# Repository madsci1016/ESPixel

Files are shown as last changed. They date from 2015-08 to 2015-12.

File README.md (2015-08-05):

# ESPixel
ESP8266 based WIFI pixel drivers. A design for both GECE (GE Color Effects) and standard WS2811 pixels. 

This work is licensed under a Creative Commons Attribution-NonCommercial 4.0 International License. This work is distributed in the hope that it will be useful, but WITHOUT ANY WARRANTY; without even the implied warranty of MERCHANTABILITY or FITNESS FOR A PARTICULAR PURPOSE.

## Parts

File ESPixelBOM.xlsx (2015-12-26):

Description | Part No | Vendor | Qty | Price/Ea | Total | 100 QTY price/ea | 100 qty price tot | Link
3.3V Reg | 497-1491-5-ND | digikey.com | 1 | 0.62 | 0.62 | 0.27 | 27
5V Reg (for 12V pixels) | LM78L05ACZFS-ND | digikey.com | 1 | 0.43 | 0.43 | 0.198 | 19.8
Capacitor Pol | 1189-2375-ND | digikey.com | 1 | 0.29 | 0.29 | 0.11008 | 11.008
Capacitor | 399-9776-ND | digikey.com | 1 | 0.29 | 0.29 | 0.1209 | 12.09
Mosfet | zvn3306a-nd | digikey.com | 1 | 0.73 | 0.73 | 0.493 | 49.3
resistor | CF18JT330RCT-ND | digikey.com | 2 | 0.1 | 0.2 | 0.02 | 4
Header | S1011E-36-ND | digikey.com | 0.33 | 2.34 | 0.7722 | 1.72 | 56.76
Diode | 1N4148TACT-ND | digikey.com | 1 | 0.1 | 0.1 | 0.0224 | 2.24
Button | 450-1650-ND | digikey.com | 1 | 0.11 | 0.11 | 0.08 | 8
8 pin socket | 1212-1231-ND | digikey.com | 1 | 0.8 | 0.8 | 0.57 | 57
Box | HM1102-ND | digikey.com | 1 | 4.19 | 4.19
Gland | 7489K12 (http://www.mcmaster.com/nav/enter.asp?partnum=7489K12) | Mcmaster-carr | 1 | 6.47 | 6.47
Gland | 7807K31 (http://www.mcmaster.com/nav/enter.asp?partnum=7807K31) | Mcmaster-carr | 1 | 3.74 | 3.74
 |  |  |  |  | 0 |  | 0
PCB |  | seeed | 0.1 | 10 | 1 | 100 | 100
 |  |  |  |  | 0 |  | 0
 |  |  |  |  | 0 |  | 0
WIFI |  | Sparkfun | 1 | 5.56 | 5.56 | 5.56 | 556
 |  |  |  |  | 0 |  | 0
 |  |  |  |  | 0 |  | 0
 |  |  |  |  | 0 |  | 0
 |  |  |  |  |  |  | 0
 |  |  |  | Total | 25.3022 |  | 903.198

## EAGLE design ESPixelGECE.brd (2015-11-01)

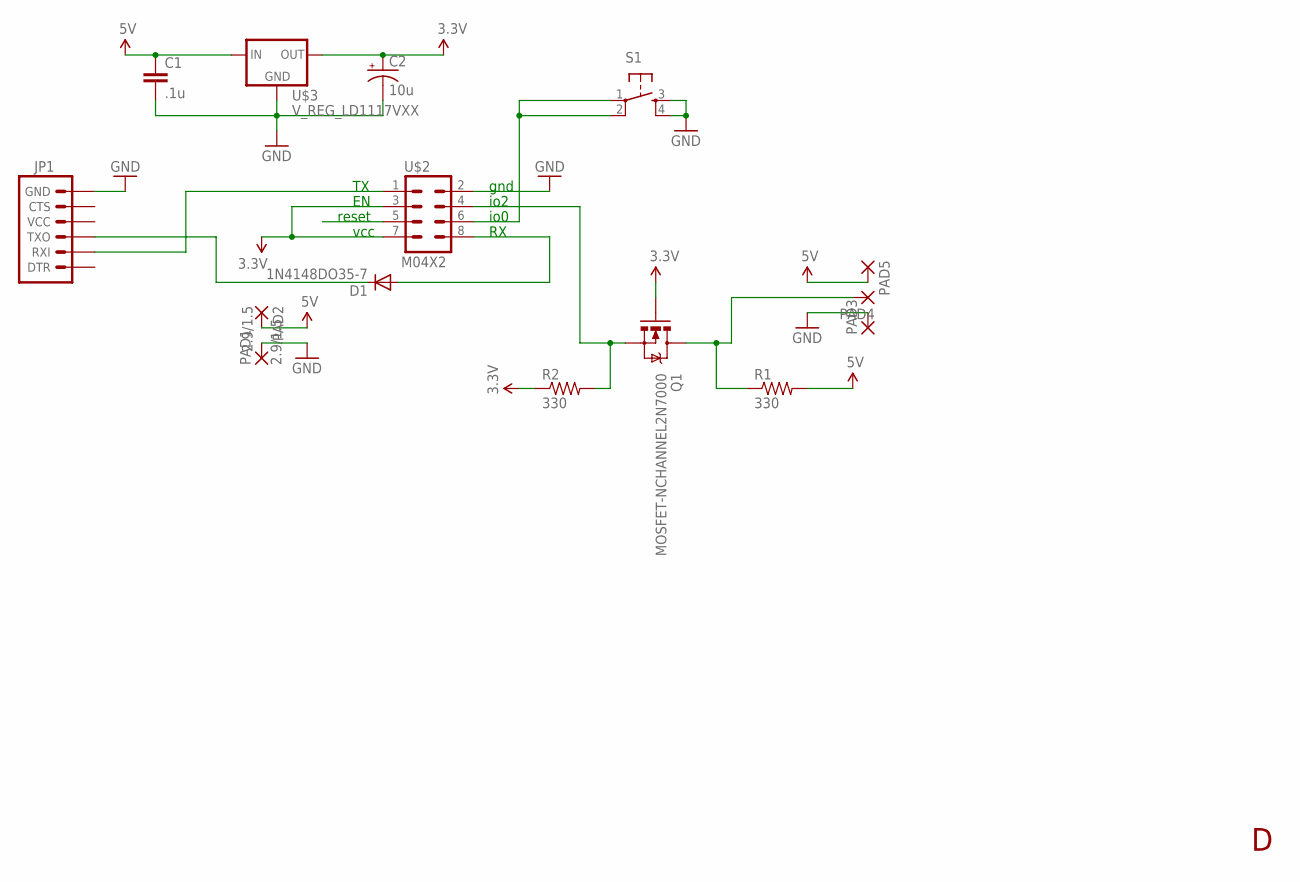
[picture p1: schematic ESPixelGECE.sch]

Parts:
C1: .1u; CAP-PTH-SMALLEZ
C2: 10u; CPOL-RADIAL-10UF-25V
D1: 1N4148DO35-7; DO35-7
JP1: ARDUINO_SERIAL_PROGRAMLOCK; 1X06_LOCK
PAD1, PAD2: 2.9/1.5
PAD3, PAD4, PAD5: 2,15/1,0
Q1: MOSFET-NCHANNEL2N7000; TO-92
R1, R2: 330; AXIAL-0.3EZ
S1: TAC_SWITCHPTH; TACTILE-PTH
U$2: M04X2; 2X4
U$3: V_REG_LD1117VXX; 78XXL

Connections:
3.3V: C2.1 (+), Q1.2 (G), R2.P$1 (1), U$2.3, U$2.7, U$3.GND (OUT)
5V: C1.1, PAD2.1, PAD5.1, R1.P$2 (2), U$3.OUT (IN)
GND: C1.2, C2.2 (-), JP1.6 (GND), PAD1.1, PAD3.1, S1.3, S1.4, U$2.2, U$3.IN (GND)
unnamed: JP1.2 (RXI), U$2.1
unnamed: D1.A, U$2.8
unnamed: PAD4.1, Q1.3 (D), R1.P$1 (1)
unnamed: S1.1, S1.2, U$2.6
unnamed: Q1.1 (S), R2.P$2 (2), U$2.4
unnamed: D1.C, JP1.3 (TXO)

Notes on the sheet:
reset
vcc
gnd
io2
io0

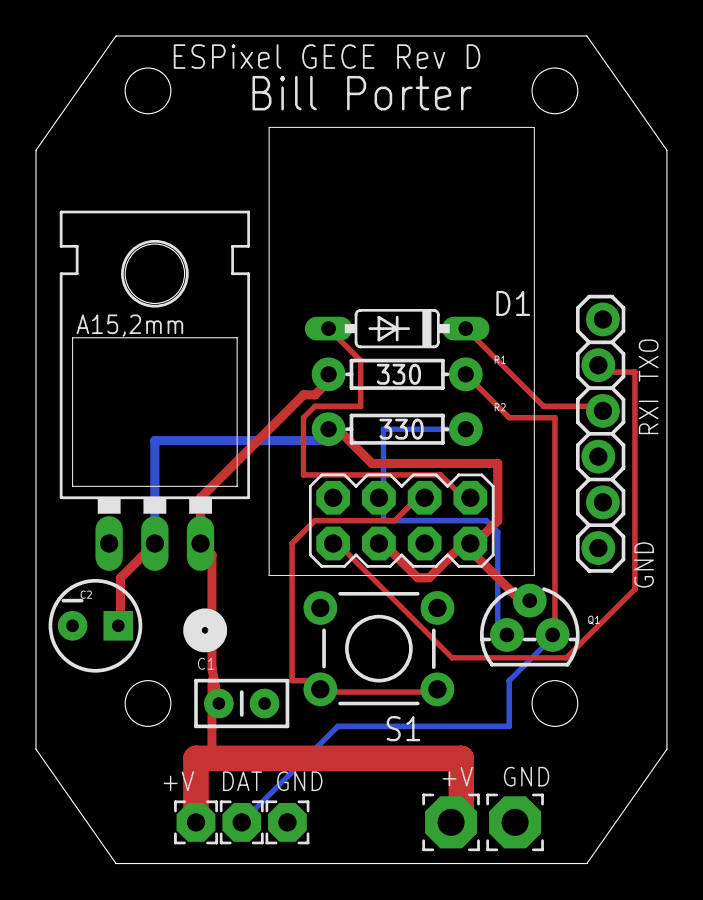
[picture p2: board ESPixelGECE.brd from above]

Board: 2 copper layers, 35.1 x 46.0 mm, 15 parts (0 on the bottom side), 9 nets.

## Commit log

2015-08-05 Added GECE design
    [ESPixelGECE.brd, ESPixelGECE.sch]
2015-08-06 Added Diode to GECE and added WS2811 version
    [ESPixel.brd, ESPixel.sch]
2015-11-01 Added BOMs, SEEED cam
    [ESPixelBOM.xlsx, ESPixelGECE.brd, ESPixelGECE.sch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]
2015-12-13 ESPixel now 12V or 5V
    Added 5V reg for 12V pixel operation.
    [ESPixel.sch, ESPixelGECEBOM.xlsx]
2015-12-13 Clean up
    [ESPixelGECEBOM.xlsx]
2015-12-26 Updated ESPixel BOM with enclosure and glands
    [ESPixelBOM.xlsx]

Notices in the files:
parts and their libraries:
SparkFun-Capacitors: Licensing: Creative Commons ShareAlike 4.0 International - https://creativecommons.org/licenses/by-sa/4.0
